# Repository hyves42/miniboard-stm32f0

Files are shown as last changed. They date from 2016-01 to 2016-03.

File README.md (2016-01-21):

miniboard-stm32f0
=================

This is the simplest bare-minimum form of a protototyping board for the stm32f030 chip from S.T.

Here is what it looks like :

Front

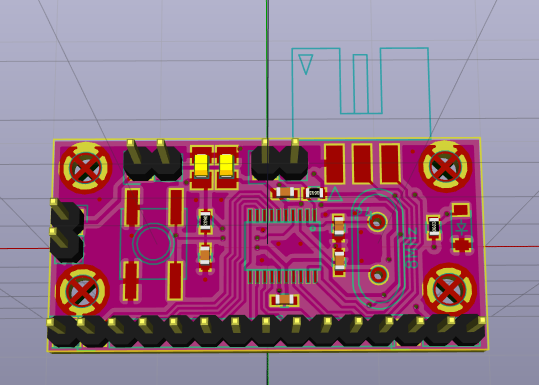
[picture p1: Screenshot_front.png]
PCB front PCB Front


Back

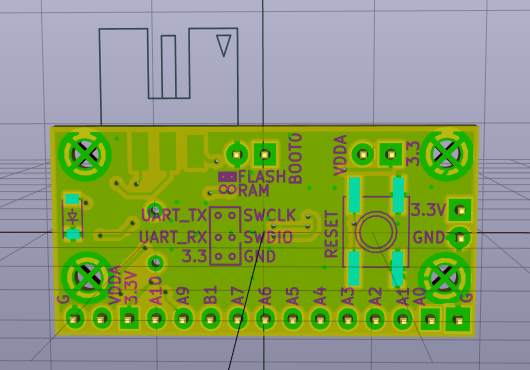
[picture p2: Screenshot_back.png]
PCB back PCB Back


The orientation of the pin headers is only indicative. 

* The long pin header row is intended to be plugged into a breadboard - back side of the board facing up.
* Other pin headers can be soldered on either side of the board depending on the usage
* Quartz is optional
* Reset button can be soldered on top or bottom side (or both)

The board is made with Kicad and requires a 2015 version for editing (with .pretty footprint libraries support)

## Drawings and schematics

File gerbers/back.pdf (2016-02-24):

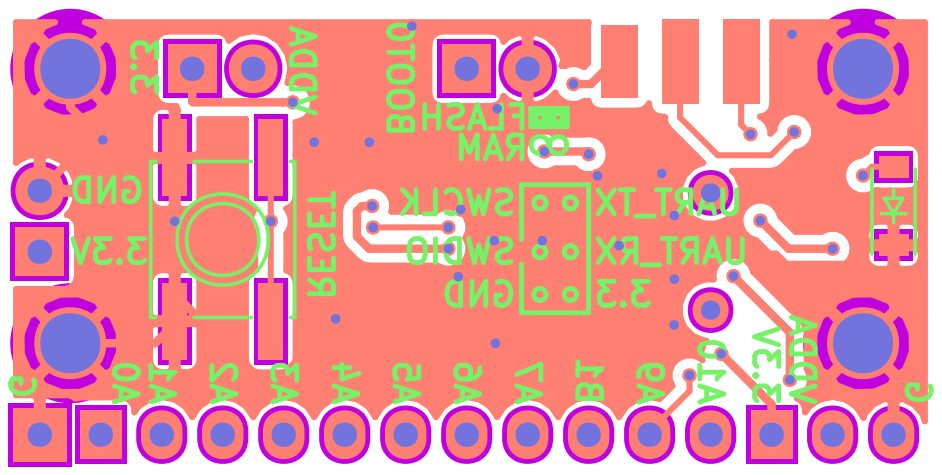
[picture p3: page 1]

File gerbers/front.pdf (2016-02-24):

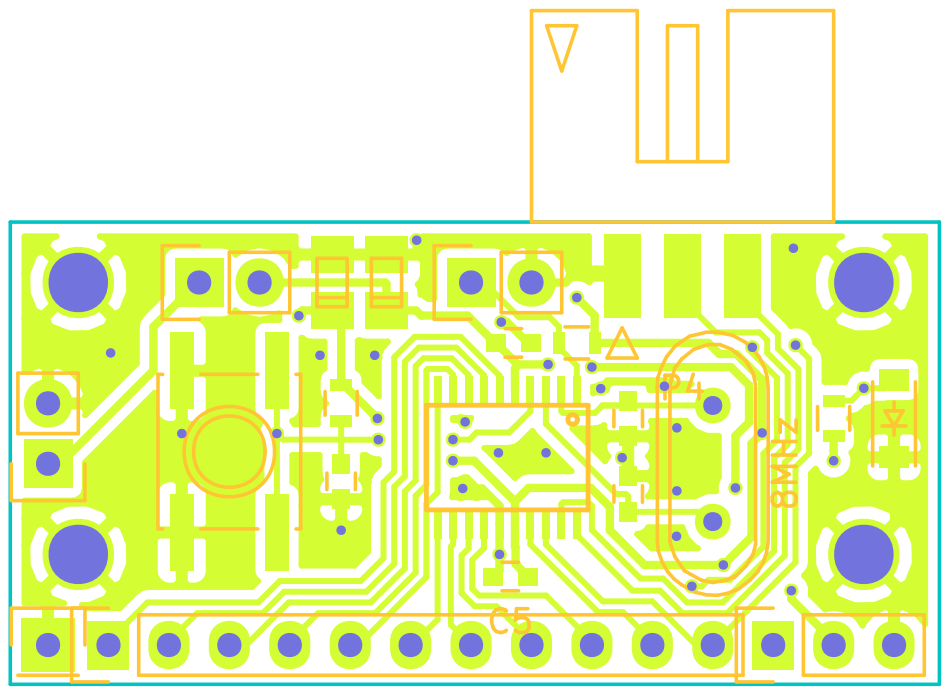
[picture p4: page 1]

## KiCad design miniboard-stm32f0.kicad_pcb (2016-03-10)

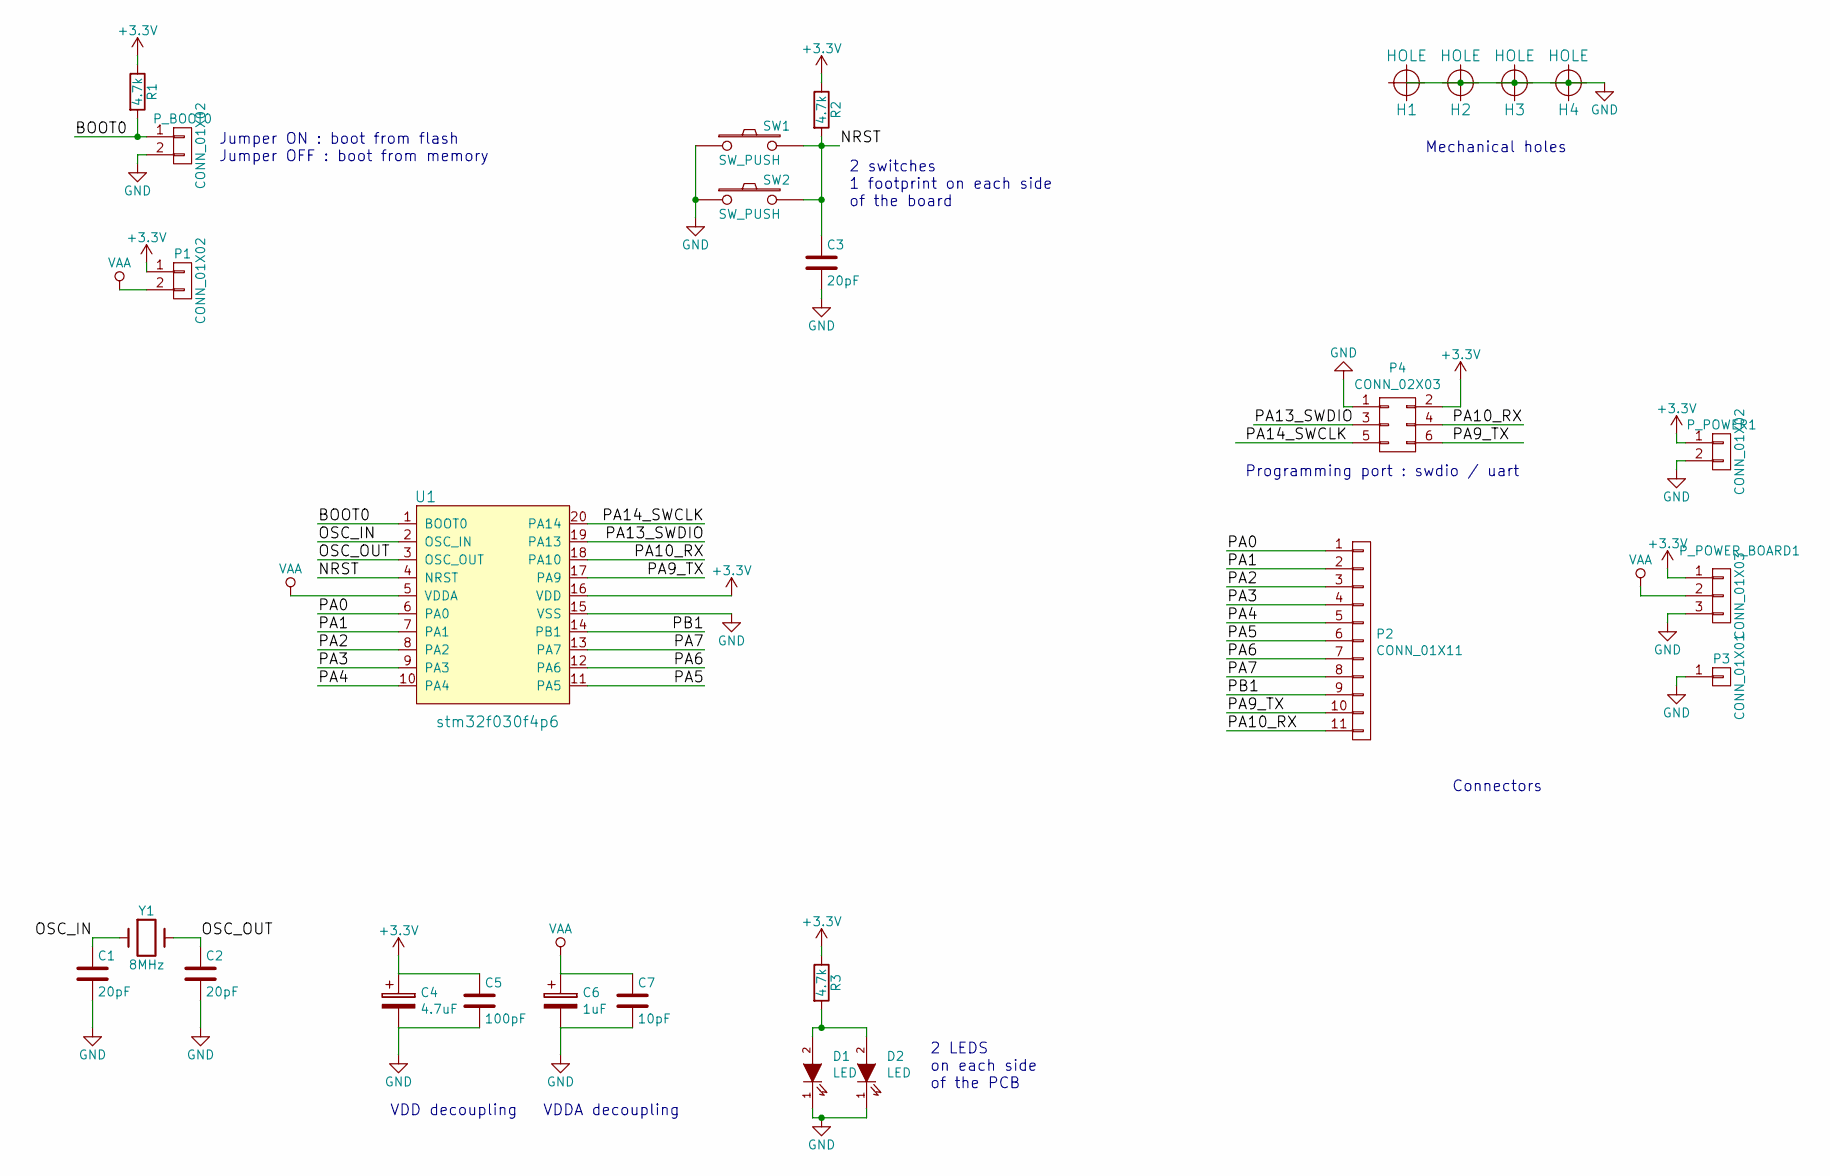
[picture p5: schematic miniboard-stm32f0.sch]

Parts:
C1, C2, C3: 20pF; C_0603
C4: 4.7uF; TantalC_SizeR_EIA-2012
C5: 100pF; C_0603
C6: 1uF; TantalC_SizeR_EIA-2012
C7: 10pF; C_0603
D1, D2: LED; SOD-123
H1, H2, H3, H4: HOLE; hole_2.5mm
P1: CONN_01X02; Pin_Header_Straight_1x02
P2: CONN_01X11; Pin_Header_Straight_1x11
P3: CONN_01X01; Pin_Header_Straight_1x01
P4: CONN_02X03; pin_header_edge_6
P_BOOT0: CONN_01X02; Pin_Header_Straight_1x02
P_POWER1: CONN_01X02; Pin_Header_Straight_1x02
P_POWER_BOARD1: CONN_01X03; Pin_Header_Straight_1x03
R1, R2, R3: 4.7k; R_0603
SW1, SW2: SW_PUSH; SW_SPST_EVQQ2
U1: stm32f030f4p6; tssop20
Y1: 8MHz; Crystal_HC49-U_Vertical

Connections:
+3V3: C4.1, C5.1, P1.1, P4.2, P_POWER1.1, P_POWER_BOARD1.1, R1.1, R2.1, R3.1, U1.16 (VDD)
/BOOT0: P_BOOT0.1, R1.2, U1.1 (BOOT0)
/NRST: C3.1, R2.2, SW1.2, SW2.2, U1.4 (NRST)
/OSC_IN: C1.1, U1.2 (OSC_IN), Y1.1
/OSC_OUT: C2.1, U1.3 (OSC_OUT), Y1.2
/PA0: P2.1, U1.6 (PA0)
/PA1: P2.2, U1.7 (PA1)
/PA2: P2.3, U1.8 (PA2)
/PA3: P2.4, U1.9 (PA3)
/PA4: P2.5, U1.10 (PA4)
/PA5: P2.6, U1.11 (PA5)
/PA6: P2.7, U1.12 (PA6)
/PA7: P2.8, U1.13 (PA7)
/PA9_TX: P2.10, P4.6, U1.17 (PA9)
/PA10_RX: P2.11, P4.4, U1.18 (PA10)
/PA13_SWDIO: P4.3, U1.19 (PA13)
/PA14_SWCLK: P4.5, U1.20 (PA14)
/PB1: P2.9, U1.14 (PB1)
GND: C1.2, C2.2, C3.2, C4.2, C5.2, C6.2, C7.2, D1.1 (K), D2.1 (K), H1.1, H2.1, H3.1, H4.1, P3.1, P4.1, P_BOOT0.2, P_POWER1.2, P_POWER_BOARD1.3, SW1.1, SW2.1, U1.15 (VSS)
unnamed: D1.2 (A), D2.2 (A), R3.2
VAA: C6.1, C7.1, P1.2, P_POWER_BOARD1.2, U1.5 (VDDA)

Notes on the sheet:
Jumper ON : boot from flash Jumper OFF : boot from memory
2 switches 1 footprint on each side of the board
VDD decoupling
VDDA decoupling
Programming port : swdio / uart
Mechanical holes
Connectors
2 LEDS on each side of the PCB

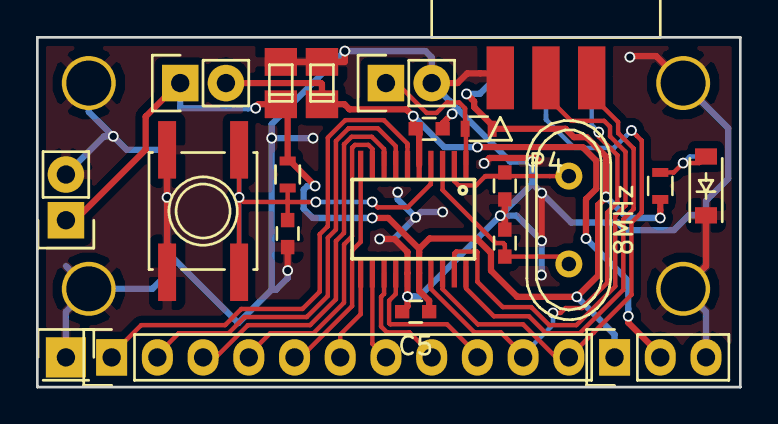
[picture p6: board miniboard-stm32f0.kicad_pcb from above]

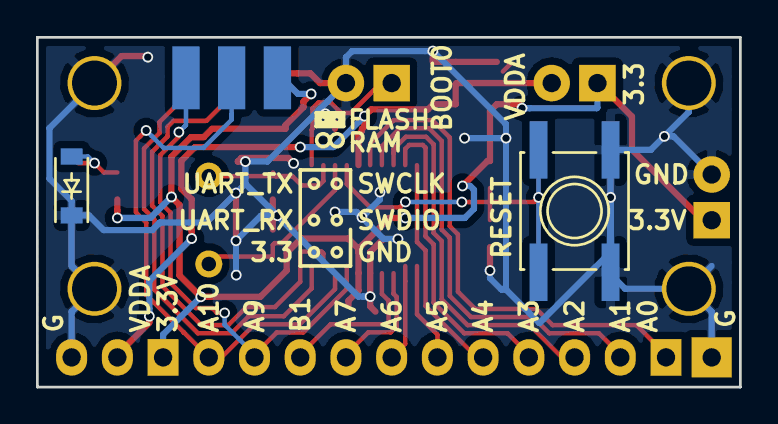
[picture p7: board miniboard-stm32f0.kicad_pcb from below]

Board: 2 copper layers, 39.1 x 19.4 mm, 27 parts (2 on the bottom side), 21 nets.

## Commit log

2015-10-13 Add stm32f0 lib
2015-10-13 Add kicad project
    [miniboard-stm32f0.kicad_pcb, miniboard-stm32f0.sch]
2015-10-14 1st version
    [miniboard-stm32f0.kicad_pcb, miniboard-stm32f0.sch]
2015-10-15 Change quartz footprint, add text
    [miniboard-stm32f0.kicad_pcb, miniboard-stm32f0.sch]
2015-10-15 Add oshw logo Generate missing gerber files
    [miniboard-stm32f0-B_Cu.gbr, miniboard-stm32f0-B_Mask.gbr, miniboard-stm32f0-B_SilkS.gbr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]
2015-10-15 move logo
    [miniboard-stm32f0.kicad_pcb]
2016-01-21 * Use edge connector for SWD and uart connector * Add power LED * Fix reset button footprint * Add decoupling caps * Realign power connector
    [miniboard-stm32f0.kicad_pcb, miniboard-stm32f0.sch]
2016-01-22 Fix minor routing issues Redraw mask
    [miniboard-stm32f0.kicad_pcb, miniboard-stm32f0.sch]
2016-01-24 Change direction of power connector
    [miniboard-stm32f0.kicad_pcb]
2016-02-24 Generate gerbers and export to pdf
    [miniboard-stm32f0-B.Cu.gbr, miniboard-stm32f0-B.Mask.gbr, miniboard-stm32f0-B.SilkS.gbr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]
2016-03-10 Fix footprint for the stm32 and the edge connector
    [miniboard-stm32f0-B.Cu.gbr, miniboard-stm32f0-B.Mask.gbr, miniboard-stm32f0-B.SilkS.gbr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]
